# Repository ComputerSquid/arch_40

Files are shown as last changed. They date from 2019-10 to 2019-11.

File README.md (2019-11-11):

## Arch 40

assembled_keyboard_1
assembled_keyboard_2

#### Case Renders:
case_render_1
case_render_2

#### Switch Plate:
switch_plate_render

## 40% Ortholinear + Columnar Stagger Keyboard
* Inspired by the Ergodox, Atreus, Iris, Corne, and probably others

* Design goals:
    * Efficiency and minimalism of a 40% form factor
    * Ergo benefits of tilted columnar stagger layout
    * Ease of use coming from ANSI style layouts
    * Simplicity of a non-split keyboard
    * Compatability with Ergodox style keysets

## Assembly:
* Stacked acrylic layer case, metal switch plate (or could also be acrylic)
    * Layer dimensions and path lengths are outlined in `path_length.md`

* Files for laser cutting by Ponoko/other services in `./illustrator_files`
    * Includes case layer DXF files imported into Adobe Illustrator at 1:1 scale with units in millimeters
    * `final_cut_layout.eps` is Ponoko's P3 size template with case layers, **without plate**
    * `final_cut_layout_plate.eps` is Ponoko's P3 size template with case layers, **with plate**

* Currently designed to be handwired with a Teensy2.0, may design a pcb later

#### Component list:
* Acrylic case layers + plate
* (49) Cherry MX style switches
* (1) 2u Cherry style **plate-mounted** stabilizer
* Teensy2.0
* Adafruit USB-mini breakout board (or a simple female USB-mini)
* WS2812B LED strips
* (49) 1N4184 diodes
* M2 Standoffs and screws (10mm length standoffs, 5mm length screws)

#### Case Stack Order:
1) `arch_40_case_layer0`
2) `arch_40_plate`
3) `arch_40_case_layer2-3`
4) `arch_40_case_layer2-3` (repeated)
5) `arch_40_case_layer4`
6) `arch_40_case_layer5`

* **Note:** `arch_40_case_layer2-3` is designed to be used twice, it contains the cutout for the USB connection
* `arch_40_case_layer4` can also be repeated to make more space for handwiring and LED strips
    * This layer can be added to the laser cut layout by copying the `arch_40_case_layer4` file and adding it to the layout
* Resulting case height with 3mm acrylic layers + 1.5mm metal plate is 16.5mm

#### Matrix:
matrix

#### Wiring Example:
wiring_example_no_led
wiring_example_with_led

#### Teensy2.0 Pinout:
* Column 0 = Backspace key column
* Row 0 = QWERTY row
~~~
Rows:               Columns:                            LED:
-----------------------------------------------------------------
r0 : F0             c0 : F7         c6 : C6             vcc : VCC
r1 : F1             c1 : B6         c7 : D3             gnd : GND
r2 : F4             c2 : B5         c8 : D2            data : B1 
r3 : F5             c3 : B4         c9 : D1
r4 : F6             c4 : D7        c10 : D0
                    c5 : C7        c11 : B7
~~~
#### Firmware Flashing:
* Linux:
    * The Teensy2.0 controller can be flashed easily with the [teensy-loader-cli](https://www.pjrc.com/teensy/loader_cli.html)

~~~
$ teensy-loader-cli -mcu=atmega32u4 -w -v ./firmware/arch40firmware.hex
~~~
* MacOS/Windows:
    * Can be flashed with the [Teensy Loader Application](https://www.pjrc.com/teensy/loader.html)
#### LED Backlighting:
* Default firmware `arch40firmware.hex` includes configuration for WS2812B LED backlighting strips
    * The data pin for the LED's is set to pin B1 on the Teensy2.0
    * Default 12 LED quantity, 10 backlight brightness levels, variable color hue
    * To change the LED configuration, the `arch40firmware.json` file can be uploaded to [Keyboard Firmware Builder](https://kbfirmware.com/) and edited/recompiled as desired

## Note:
* Kerf of plate and case layers is set to 0.15mm (typical for Ponoko/ Laserboost/ Lasergist)

## To-do:
* Add PCB files

###### Model was created in Solidworks, then exported as STL/DXF. Feel free to use/modify/redistribute.

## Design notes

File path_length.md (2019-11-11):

### Dimensions and path lengths of DXF files to confirm scaling

* `arch_40_case_layer0.dxf` 
    * Height: 147 mm
    * Width: 300 mm
    * Path Length: 2186 mm

* `arch_40_plate.dxf` 
    * Height: 147 mm
    * Width: 300 mm
    * Path Length: 3859 mm

* `arch_40_case_layer2-3.dxf` 
    * Height: 147 mm
    * Width: 300 mm
    * Path Length:  1915 mm

* `arch_40_case_layer4.dxf` 
    * Height: 147 mm
    * Width: 300 mm
    * Path Length: 1927 mm

* `arch_40_case_layer5.dxf` 
    * Height: 147 mm
    * Width: 300 mm
    * Path Length: 1015 mm

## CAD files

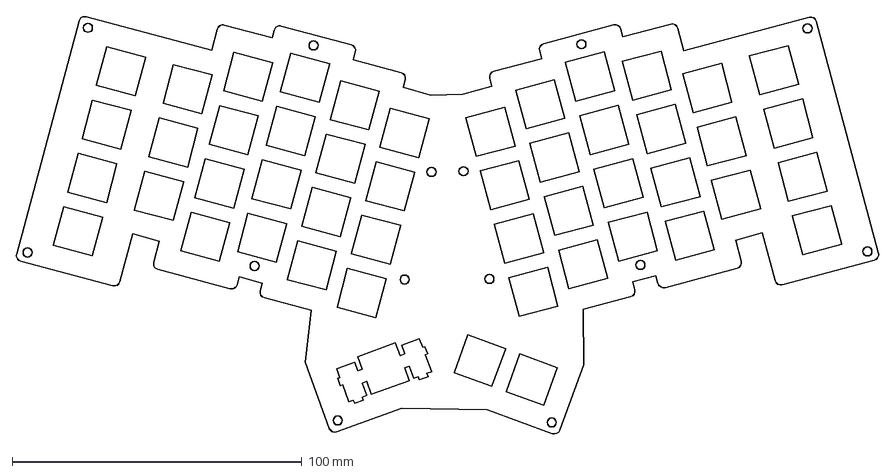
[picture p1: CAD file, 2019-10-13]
arch_40_plate_sqmx.DXF
297.5 x 144.3 mm

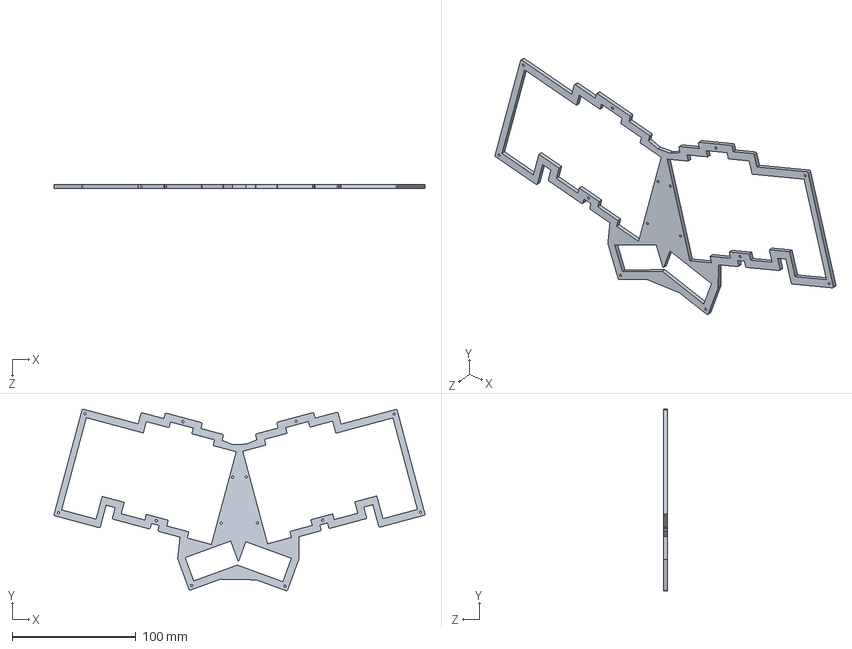
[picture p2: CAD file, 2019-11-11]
cad_files/sldprt_files/arch_40_case_layer0.SLDPRT
300.3 x 147.0 x 3.00 mm

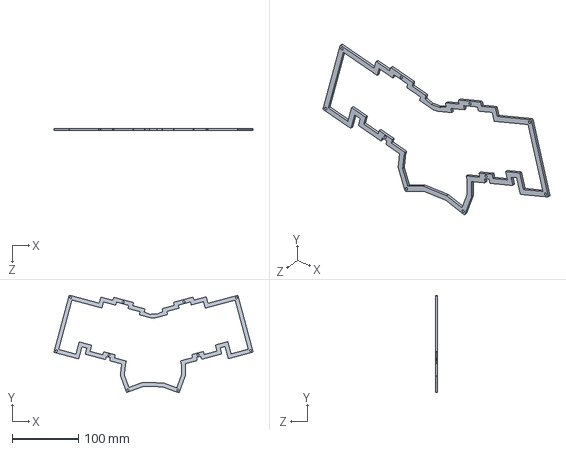
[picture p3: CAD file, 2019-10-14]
cad_files/sldprt_files/arch_40_case_layer4.SLDPRT
300.3 x 147.0 x 3.00 mm

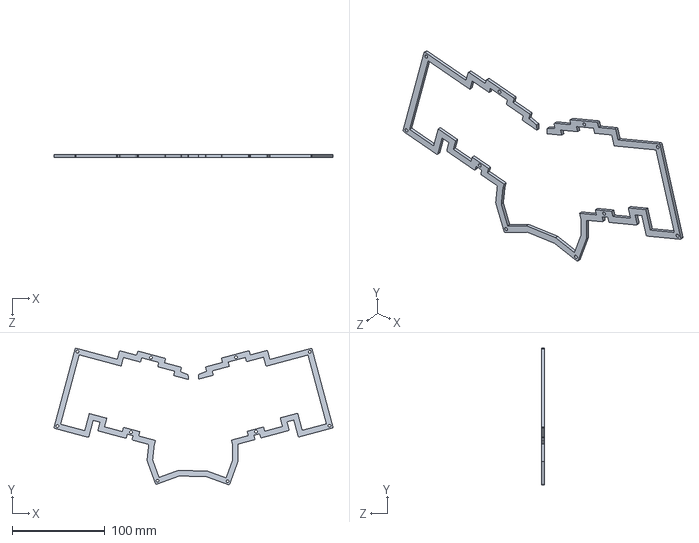
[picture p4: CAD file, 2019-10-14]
cad_files/sldprt_files/arch_40_case_layer2-3.SLDPRT
300.3 x 147.0 x 3.00 mm

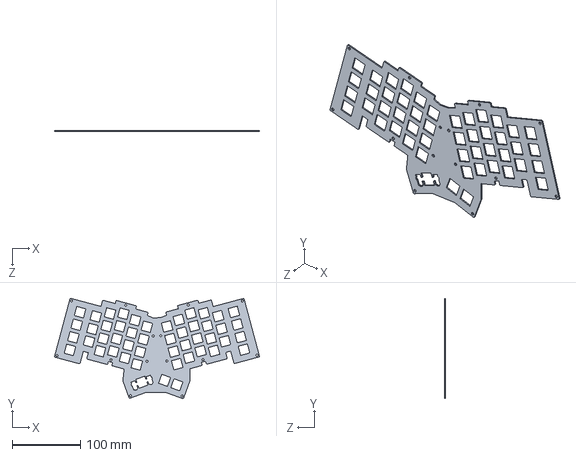
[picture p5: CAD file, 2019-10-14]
cad_files/sldprt_files/arch_40_plate.SLDPRT
300.3 x 147.0 x 1.50 mm

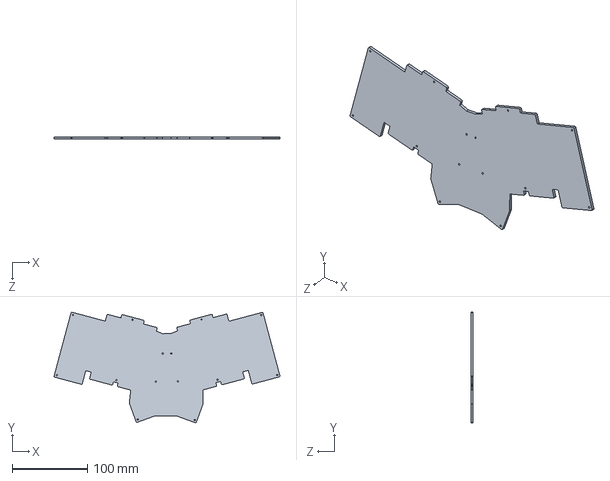
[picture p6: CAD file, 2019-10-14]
cad_files/sldprt_files/arch_40_case_layer5.SLDPRT
300.3 x 147.0 x 3.00 mm

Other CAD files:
cad_files/dxf_files/arch_40_case_layer0.DXF
cad_files/dxf_files/arch_40_case_layer2-3.DXF
cad_files/dxf_files/arch_40_case_layer4.DXF
cad_files/dxf_files/arch_40_case_layer5.DXF
cad_files/dxf_files/arch_40_plate.DXF
cad_files/stl_files/arch_40_case_layer0.STL
cad_files/stl_files/arch_40_case_layer2-3.STL
cad_files/stl_files/arch_40_case_layer4.STL
cad_files/stl_files/arch_40_case_layer5.STL
cad_files/stl_files/arch_40_plate.STL

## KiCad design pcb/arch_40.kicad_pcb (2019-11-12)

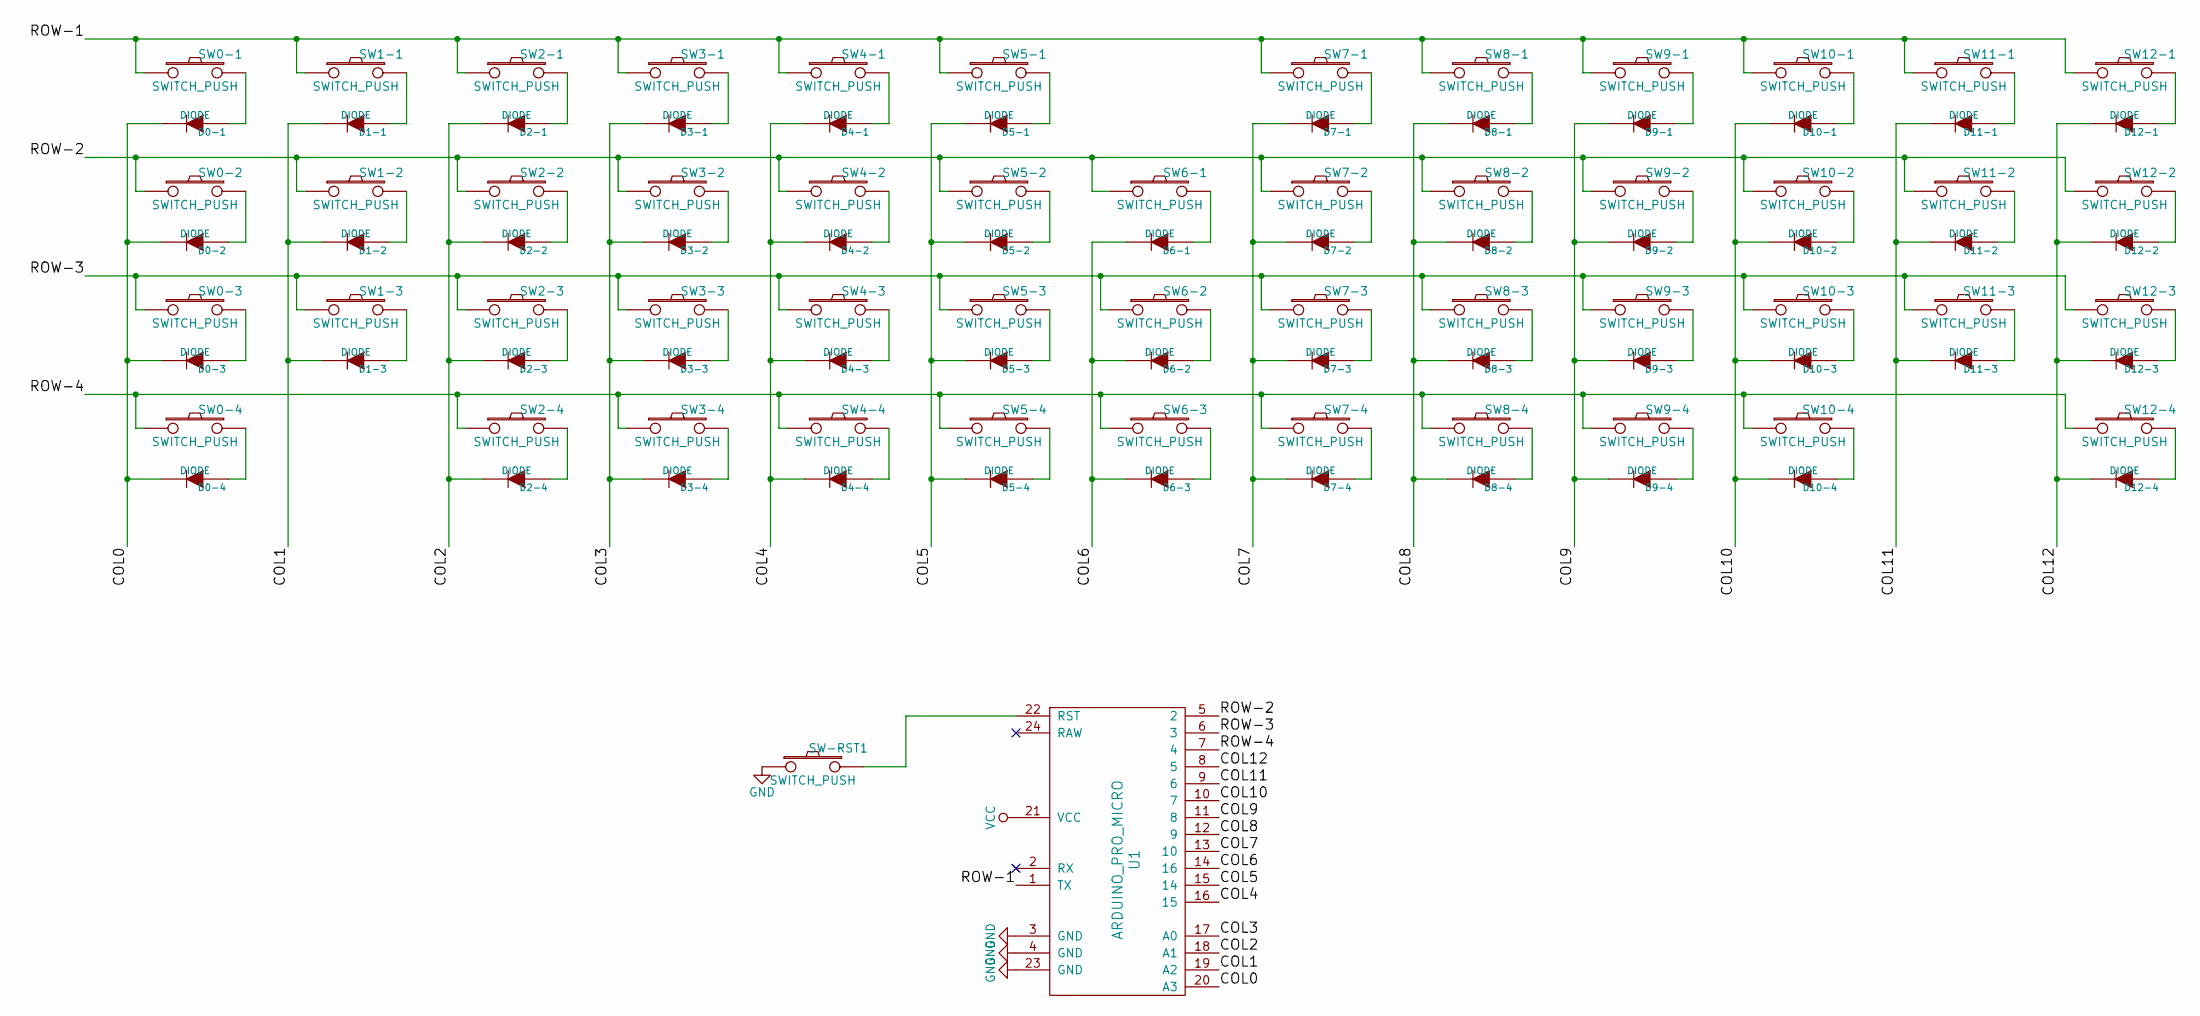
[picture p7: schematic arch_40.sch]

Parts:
D0-1, D0-2, D0-3, D0-4, D1-1, D1-2, D1-3, D2-1, D2-2, D2-3, D2-4, D3-1, D3-2, D3-3, D3-4, D4-1, D4-2, D4-3, D4-4, D5-1, D5-2, D5-3, D5-4, D6-1, D6-2, D6-3, D7-1, D7-2, D7-3, D7-4, D8-1, D8-2, D8-3, D8-4, D9-1, D9-2, D9-3, D9-4, D10-1, D10-2, D10-3, D10-4, D11-1, D11-2, D11-3, D12-1, D12-2, D12-3, D12-4: DIODE; Diode
SW0-1, SW0-2, SW0-3, SW0-4, SW12-1, SW12-2, SW12-3, SW12-4: SWITCH_PUSH; MXOnly-1.5U-NoLED
SW1-1, SW1-2, SW1-3, SW2-1, SW2-2, SW2-3, SW2-4, SW3-1, SW3-2, SW3-3, SW3-4, SW4-1, SW4-2, SW4-3, SW4-4, SW5-1, SW5-2, SW5-3, SW5-4, SW6-1, SW6-2, SW7-1, SW7-2, SW7-3, SW7-4, SW8-1, SW8-2, SW8-3, SW8-4, SW9-1, SW9-2, SW9-3, SW9-4, SW10-1, SW10-2, SW10-3, SW10-4, SW11-1, SW11-2, SW11-3: SWITCH_PUSH; MXOnly-1U-NoLED
SW6-3: SWITCH_PUSH; MXOnly-2U-NoLED
SW-RST1: SWITCH_PUSH; Diode
U1: ARDUINO_PRO_MICRO; ArduinoProMicro

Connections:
/COL0: D0-1.2 (K), D0-2.2 (K), D0-3.2 (K), D0-4.2 (K), U1.20 (A3)
/COL1: D1-1.2 (K), D1-2.2 (K), D1-3.2 (K), U1.19 (A2)
/COL2: D2-1.2 (K), D2-2.2 (K), D2-3.2 (K), D2-4.2 (K), U1.18 (A1)
/COL3: D3-1.2 (K), D3-2.2 (K), D3-3.2 (K), D3-4.2 (K), U1.17 (A0)
/COL4: D4-1.2 (K), D4-2.2 (K), D4-3.2 (K), D4-4.2 (K), U1.16 (15)
/COL5: D5-1.2 (K), D5-2.2 (K), D5-3.2 (K), D5-4.2 (K), U1.15 (14)
/COL6: D6-1.2 (K), D6-2.2 (K), D6-3.2 (K), U1.14 (16)
/COL7: D7-1.2 (K), D7-2.2 (K), D7-3.2 (K), D7-4.2 (K), U1.13 (10)
/COL8: D8-1.2 (K), D8-2.2 (K), D8-3.2 (K), D8-4.2 (K), U1.12 (9)
/COL9: D9-1.2 (K), D9-2.2 (K), D9-3.2 (K), D9-4.2 (K), U1.11 (8)
/COL10: D10-1.2 (K), D10-2.2 (K), D10-3.2 (K), D10-4.2 (K), U1.10 (7)
/COL11: D11-1.2 (K), D11-2.2 (K), D11-3.2 (K), U1.9 (6)
/COL12: D12-1.2 (K), D12-2.2 (K), D12-3.2 (K), D12-4.2 (K), U1.8 (5)
/ROW-1: SW0-1.1, SW1-1.1, SW2-1.1, SW3-1.1, SW4-1.1, SW5-1.1, SW7-1.1, SW8-1.1, SW9-1.1, SW10-1.1, SW11-1.1, SW12-1.1, U1.1 (TX)
/ROW-2: SW0-2.1, SW1-2.1, SW2-2.1, SW3-2.1, SW4-2.1, SW5-2.1, SW6-1.1, SW7-2.1, SW8-2.1, SW9-2.1, SW10-2.1, SW11-2.1, SW12-2.1, U1.5 (2)
/ROW-3: SW0-3.1, SW1-3.1, SW2-3.1, SW3-3.1, SW4-3.1, SW5-3.1, SW6-2.1, SW7-3.1, SW8-3.1, SW9-3.1, SW10-3.1, SW11-3.1, SW12-3.1, U1.6 (3)
/ROW-4: SW0-4.1, SW2-4.1, SW3-4.1, SW4-4.1, SW5-4.1, SW6-3.1, SW7-4.1, SW8-4.1, SW9-4.1, SW10-4.1, SW12-4.1, U1.7 (4)
GND: SW-RST1.1, U1.3 (GND), U1.4 (GND), U1.23 (GND)
unnamed: D0-1.1 (A), SW0-1.2
unnamed: D0-2.1 (A), SW0-2.2
unnamed: D0-3.1 (A), SW0-3.2
unnamed: D0-4.1 (A), SW0-4.2
unnamed: D1-1.1 (A), SW1-1.2
unnamed: D1-2.1 (A), SW1-2.2
unnamed: D1-3.1 (A), SW1-3.2
unnamed: D2-1.1 (A), SW2-1.2
unnamed: D2-2.1 (A), SW2-2.2
unnamed: D2-3.1 (A), SW2-3.2
unnamed: D2-4.1 (A), SW2-4.2
unnamed: D3-1.1 (A), SW3-1.2
unnamed: D3-2.1 (A), SW3-2.2
unnamed: D3-3.1 (A), SW3-3.2
unnamed: D3-4.1 (A), SW3-4.2
unnamed: D4-1.1 (A), SW4-1.2
unnamed: D4-2.1 (A), SW4-2.2
unnamed: D4-3.1 (A), SW4-3.2
unnamed: D4-4.1 (A), SW4-4.2
unnamed: D5-1.1 (A), SW5-1.2
unnamed: D5-2.1 (A), SW5-2.2
unnamed: D5-3.1 (A), SW5-3.2
unnamed: D5-4.1 (A), SW5-4.2
unnamed: D6-1.1 (A), SW6-1.2
unnamed: D6-2.1 (A), SW6-2.2
unnamed: D6-3.1 (A), SW6-3.2
unnamed: D7-1.1 (A), SW7-1.2
unnamed: D7-2.1 (A), SW7-2.2
unnamed: D7-3.1 (A), SW7-3.2
unnamed: D7-4.1 (A), SW7-4.2
unnamed: D8-1.1 (A), SW8-1.2
unnamed: D8-2.1 (A), SW8-2.2
unnamed: D8-3.1 (A), SW8-3.2
unnamed: D8-4.1 (A), SW8-4.2
unnamed: D9-1.1 (A), SW9-1.2
unnamed: D9-2.1 (A), SW9-2.2
unnamed: D9-3.1 (A), SW9-3.2
unnamed: D9-4.1 (A), SW9-4.2
unnamed: D10-1.1 (A), SW10-1.2
unnamed: D10-2.1 (A), SW10-2.2
unnamed: D10-3.1 (A), SW10-3.2
unnamed: D10-4.1 (A), SW10-4.2
unnamed: D11-1.1 (A), SW11-1.2
unnamed: D11-2.1 (A), SW11-2.2
unnamed: D11-3.1 (A), SW11-3.2
unnamed: D12-1.1 (A), SW12-1.2
unnamed: D12-2.1 (A), SW12-2.2
unnamed: D12-3.1 (A), SW12-3.2
unnamed: D12-4.1 (A), SW12-4.2
unnamed: SW-RST1.2, U1.22 (RST)

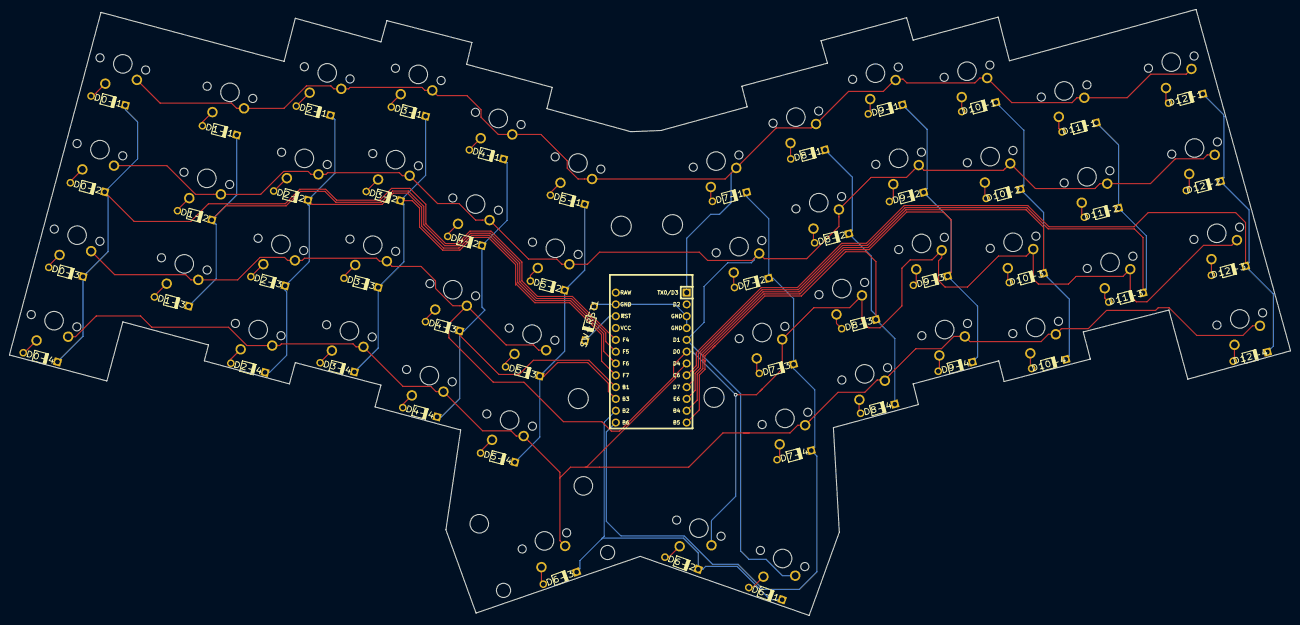
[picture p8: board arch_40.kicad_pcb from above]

Board: 2 copper layers, 275.5 x 130.3 mm, 100 parts (1 on the bottom side), 68 nets.

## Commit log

2019-10-12 added switch plate dxf
    [arch_40_switchplate.dxf]
2019-10-13 added switch plate sldprt, stl, and dxf
    [arch_40_plate_sqmx.DXF, arch_40_plate_sqmx.SLDPRT, arch_40_plate_sqmx.STL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]
2019-10-14 added case cad files, updated readme
    [arch_40_case_layer0.DXF, arch_40_case_layer0.SLDPRT, arch_40_case_layer0.STL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]
2019-10-14 separated cad files into directories
    [arch_40_case_layer0.DXF, arch_40_case_layer0.SLDPRT, arch_40_case_layer0.STL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]
2019-10-14 removed layout image
    [arch_40_case_layer0.DXF, arch_40_case_layer0.SLDPRT, arch_40_case_layer0.STL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]
2019-10-27 added LED config
2019-11-11 fixed layer0 cad files
    [arch_40_case_layer0.DXF, arch_40_case_layer0.SLDPRT, arch_40_case_layer0.STL]
2019-11-11 added plate to illustrator files
2019-11-11 updated cut layout, added layout with plate
2019-11-11 updated layer0 and path length
    [arch_40_case_layer0.DXF]
2019-11-11 pcb. placed the footprints.
    [arch_40-2019-11-11-19-06-58.sch, arch_40-2019-11-11-19-08-17.sch, arch_40-2019-11-11-19-10-08.sch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]
2019-11-11 pcb. placed the footprints accordingly.
    [arch_40.kicad_pcb]
2019-11-12 cut and routed.
2019-11-12 added holes to match the cutout.
    [arch_40.kicad_pcb]
